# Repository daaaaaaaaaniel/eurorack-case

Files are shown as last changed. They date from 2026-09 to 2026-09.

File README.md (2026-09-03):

# eurorack-case

A parametric Eurorack case with a sloped floor in [CadQuery](https://cadquery.readthedocs.io),
ported from two Onshape Part Studios (`Eurorack v1 sym` / `asym`) and verified
against their STEP exports.

There is also a browser version at
<https://daaaaaaaaaniel.github.io/eurorack-case/> that builds the same case
without installing anything. [UserManual.md](UserManual.md) explains every
control on that page.

```
pip install cadquery
python3 build.py                                  # 26 HP, 30/30 mm walls, round lips
python3 build.py --hp 84 --front 30 --rear 80 --top-lips chamfer --tab-clearance 0.2
python3 build.py --variant asym                   # one end an integral wall, one cap
python3 -m pytest tests
```

`build.py` writes STEP and STL for each part, plus an assembly STEP, into
`output/`.

## Parts

- **case** — sloped-floor shell with T-slot rails under a 2 mm panel recess and
  counterbored M3 screw holes for the end caps. Open at both ends (`sym`), or
  closed at one end by an integral wall (`asym`, `left_wall=True`).
- **end_cap_left / end_cap_right** — 4 mm plate with a 5 mm tab that plugs into
  the shell and carries square M3 nut traps behind every screw.
- **blank_panel** — a blank module panel for checking the rail spacing.

## Configuration

The same nine inputs as the Onshape configuration, on `CaseParams`:
`hp_count`, `front_height`, `rear_height`, `top_lips` / `upper_round` /
`upper_chamfer`, `bottom_lips` / `lower_round` / `lower_chamfer`. Every other
design constant is a field too (`eurorack_case/params.py`), named after the
Onshape variable it came from.

```python
from eurorack_case import CaseParams, case, end_cap

p = CaseParams(hp_count=42, rear_height=60, top_lips="chamfer")
shell = case(p)
cap = end_cap(p, "left")
```

## Layout

- `eurorack_case/` — the model (`params.py`, `parts.py`)
- `build.py` — CLI exporter
- `tests/` — geometry checks: parts are valid, caps fit without clashing,
  screws pass the wall into the tab, nut traps sit behind them, lip styles and
  a parameter sweep build
- `viewer/` — a browser viewer (Three.js). `python3 viewer/make_viewer.py`
  embeds the exact meshes into `viewer/dist/eurorack-asym-case.html`; the page
  also rebuilds either variant in JavaScript when you move its sliders — profile
  extrusions with the screw holes, counterbores and nut traps cut by CSG
  (`viewer/vendor/csg.js`, MIT), within 0.01 % of the CadQuery volumes — and
  can save what it is showing as ASCII STL (published as a Claude artifact
  with the `downloads` capability; the host allows no `.stl` extension, so the
  file arrives as `.stl.txt` to be renamed)
- `docs/port-notes.md` — what maps to what, and where the port deliberately
  differs from the source (read this)
- `docs/port-feasibility.md` — the pre-port assessment
- `tools/fs_inventory.py` — inventory extractor for the Onshape export
- `reference/Eurorackv1asym.fs`, `Eurorackv1sym.fs` — the source FeatureScript
- `reference/onshape/` — Onshape's STEP exports of both variants, which
  `tests/test_matches_onshape.py` checks the port against
- `poc/` — the feasibility spike

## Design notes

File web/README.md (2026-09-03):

# eurorack-case-web

The case configurator as a static web app: the model in
[replicad](https://replicad.xyz) (OpenCascade compiled to wasm, running in a
web worker), a three.js viewer, and STL / STEP export straight from the
browser. Same geometry as the CadQuery model, verified against the Onshape
exports.

```
npm install
npm run dev        # http://localhost:5173
npm test           # builds every part in Node, compares with reference/onshape/*.step
npm run typecheck
npm run build      # -> dist/ (~23 MB, of which the wasm is 23 MB raw / 7 MB gzipped)
```

## Layout

- `src/model/params.ts` — `caseParams()`: the fields of `CaseParams` in
  `eurorack_case/params.py`, camel-cased, plus the derived values.
- `src/model/parts.ts` — `caseShell()`, `endCap()`, `blankPanel()`: a
  line-for-line port of `eurorack_case/parts.py`, with replicad edge finders
  where the Python matched edges by center point.
- `src/filename.ts` — `partFileName()`: a part is named for itself and the
  parameters that shape it, so two files with one name hold one geometry.
- `src/config.ts` — `buildConfig()` / `parseConfig()`: the saved settings, and
  a reader that treats an imported file as untrusted.
- `src/oc.ts` — `initOC()`: starts the wasm kernel and hands it to replicad.
- `src/worker.ts` — the modeling worker: builds the parts on request, returns
  meshes + edge lines + volumes, and writes STL/STEP on demand — one part in
  one format as itself, anything more zipped with its configuration.
- `src/scene.ts`, `src/main.ts`, `index.html` — the viewer and its controls.
- `test/matches-onshape.test.ts` — volume (1e-5), face count and bounding
  extents against Onshape's exports for both variants, plus a parameter sweep.
- `test/config.test.ts`, `test/filename.test.ts` — the configuration round trip
  (including files that are hand-edited, from a later version, or not ours) and
  the naming rule. Both run without the kernel, in milliseconds.
- `scripts/smoke.mjs` — drives the built app in headless Chromium over the
  DevTools protocol: first build, a rebuild, the asym variant, a zip download
  read back out of its central directory, a one-part zip, a config-only
  download, a single part, and a config import.

## Downloads

**Download** writes `case.zip`: the parts ticked under Parts, in STL, STEP or
both, plus a `config.json` of the settings that produced them. With nothing
ticked, the `config.json` comes down on its own. **More options** holds a
single part on its own, as a bare file. Members are named for the part and what shapes it —
`case_26hp_30mm-front_45mm-rear.stl`, `capL_30mm-front_45mm-rear.stl`,
`panel_6hp.stl` — so the caps carry no HP, being a cross-section that does not
change with the case's width.

**Import config** reads a `config.json` back and puts every control where it was,
so a case can be reprinted, or adjusted and reprinted, months later. Only the
settings the page exposes are saved; everything else follows the current model.
An imported file is checked field by field, and anything corrected is reported.

## Limits the kernel imposes

- A top lip must be smaller than the wall thickness: the wall top is only that
  wide before it drops into the panel recess, so a larger fillet has no face to
  land on. `caseParams()` refuses it; the page's slider stops at 3.5 mm.
- The end cap's 1.5 mm outer edge break is only built when the lips are modest
  (rounds ≤ 5 mm, chamfers ≤ 2 mm). Beyond that OpenCascade does not fail — it
  returns a plausible-looking solid with a wrong volume — so `endCap()` leaves
  the break off and checks the volume of what it built against the un-cut plate
  and tab. The Onshape source has the same blend and would have the same
  trouble; its defaults (1 mm) are well inside the sound region.

## Deploying to GitHub Pages

`.github/workflows/pages.yml` builds `web/`, runs the tests, and deploys
`web/dist` on every push that touches `web/` (branches `claude/replicad-port`
and `main`), or by hand from the Actions tab. One-time setup in the repository:
**Settings → Pages → Source: GitHub Actions**. The site then lives at
`https://<user>.github.io/eurorack-case/`.

The kernel is single-threaded, so no cross-origin-isolation headers are
needed — Pages can serve it as plain static files. First visit downloads the
23 MB wasm (7 MB if the CDN gzips it); after that it is cached.

## Timings

In headless Chromium on a laptop-class CPU: kernel start ~10 s on a cold
cache, first build ~2 s, a rebuild ~1–2 s, STL or STEP export well under a
second.

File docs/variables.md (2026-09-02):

# Onshape variables → `CaseParams`

The Part Studio's variable table (as shown in Onshape) against the port. "Used"
means a live sketch dimension or feature references the variable; several are
defined but never referenced, and the geometry shows what the sketches actually
drew.

| Onshape variable | value | `CaseParams` | port default | note |
|---|---|---|---|---|
| `HP_Count` | `#HP_Count0` | `hp_count` | 26 | configuration input |
| `HP` | 5.08 | `HP` (module constant) | 5.08 | |
| `CaseRearHeight` | `#RearHeight` | `rear_height` | 30 | configuration input |
| `CaseFrontHeight` | 33 | — | | **not used**: the front wall is dimensioned to the `Front_Height` configuration input (30); `front_height` |
| `CaseFrontBackThickness` | 4 | `wall_thickness` | 4 | |
| `CaseBottomThickness` | 4 | `bottom_thickness` | 4 | |
| `PanelHeight` | 129.5 | `panel_height` | 129.5 | clear width between the inner walls |
| `PanelThickness` | 2 | `panel_thickness` | 2 | depth of the panel recess |
| `PanelHoleVerticalInset` | 3 | `panel_hole_edge_inset` | 3 | |
| `RailBlockDepth` | 8 | `rail_depth` | **7.798472** | **not used**: the rail sketch carries a bare 7.798; the STEP export confirms it |
| `RailBlockHeight` | 16 | `rail_height` | **10** | **not used**: the block is drawn 10 tall; the STEP export confirms it |
| `RailBlockPanelInset` | 3 | `rail_inset` | 3 | bolt-slot axis from the inner wall |
| `RailBlockBoltWidth` | 3.2 | `rail_bolt_width` | 3.2 | |
| `RailBlockBoltDepth` | 8 | `rail_bolt_depth` | 8 | |
| `RailBlockNutWidth` | 5.8 | `rail_nut_width` | 5.8 | nut traps in the tab are cut `#RailBlockNutWidth - .1mm` |
| — | (undimensioned) | `rail_nut_slot_width` | **5.596945** | the rail's sliding-nut slot has no dimension; solved value, confirmed by the STEP |
| `RailBlockNutThickness` | 2.5 | `rail_nut_thickness` | 2.5 | |
| `RailBlockNutDepth` | 2 | `rail_nut_depth` | 2 | |
| `EndCapThickness` | `#CaseFrontBackThickness` | `end_cap_thickness` | 4 | |
| `EndCapTabThickness` | 5 | `end_cap_tab_thickness` | 5 | |
| `EndCapTabDepth` | `#BottomHoleInset + .7*#BoltCounterboreDiam` | `end_cap_tab_depth` (derived) | 8.2 | |
| `BoltThrougDiam` | 3.3 | `bolt_through_diam` | 3.3 | |
| `BoltCounterboreDiam` | 6 | `bolt_counterbore_diam` | 6 | |
| `BoltCounterboreThick` | 1.75 | `bolt_counterbore_depth` | 1.75 | |
| `BottomHoleInset` | 4 | `bottom_hole_inset` | 4 | screw axis from the case end |
| `BottomHoleSpacing` | 55 | `bottom_hole_spacing` | 55 | |
| `RearHoleSpacing` | 23 | `wall_hole_spacing` | 23 | used for both walls |
| `BaseCase` | measured, 137.5 | `outer_depth` (derived) | 137.5 | = `panel_height + 2 * wall_thickness` |
| `BaseCaseInset` | `#BaseCase - 3*#CaseFrontBackThickness` = 125.5 | — | | **not used** |
| `Railbolt_to_railbolt` | 123 | — | | **not used**; the rails are actually `panel_height - 2 * rail_inset` = 123.5 apart |
| `Rail_Length` | 56 | — | | **not used** |
| `BoltPlane_PanelEnd` | 3 | — | | **not used** |
| `UpperRoundDiam` | 2 | — | | **not used**: the fillet takes the `Upper_Round` configuration input (1); `upper_round` |
| `UpperChamfer` | 2 | — | | **not used**: the chamfer takes `Upper_Chamfer` (1); `upper_chamfer` |
| `LowerRoundDiam` | 0 | — | | drives only `Fillet 2`, which a 0 mm radius makes a no-op |
| `LowerChamfer` | 2 | — | | **not used**: the chamfer takes `Lower_Lip_Bevel` (1); `lower_chamfer` |

Configuration inputs not in the variable table: `Front_Height`, `Upper_Round`,
`Upper_Chamfer`, `Lower_Round`, `Lower_Lip_Bevel`, and the two lip-style enums —
`front_height`, `upper_round`, `upper_chamfer`, `lower_round`, `lower_chamfer`,
`top_lips`, `bottom_lips`.

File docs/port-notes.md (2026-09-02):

# Port notes

How `eurorack_case/` relates to the Onshape source, and where it deliberately
differs. Read `port-feasibility.md` first for what the source contains.

## Verified against Onshape

`reference/onshape/` holds STEP exports of both Part Studios at the default
configuration, and `tests/test_matches_onshape.py` checks the port against
them. Every part matches to better than 0.001 % in volume with identical face
counts and bounding extents:

| Onshape export | port | volume |
|---|---|---|
| `sym` Part 7 (case) | `case(CaseParams())` | 111.5710 cm³ |
| `sym` Part 6 / endcap | `end_cap(p, "left")` / `"right"` | 21.7197 cm³ |
| `asym` case | `case(CaseParams(left_wall=True))` | 128.4112 cm³ |
| `asym` endcap | `end_cap(p, "right")` | 21.7197 cm³ |

## The two Part Studios

`Eurorack v1 sym` and `Eurorack v1 asym` are the same design with different
ends, not different wall heights (both default to 30/30 mm):

- **sym** — shell open at both ends, two removable end caps. `left_wall=False`.
- **asym** — X = 0 closed by an integral 4 mm wall with the outer profile, one
  removable cap at the far end, no screw holes at the closed end. `left_wall=True`.

The `sym` source is the `asym` source plus four features (`Plane 1`, `Split 4`,
`Mirror 3`, `Boolean 1`) that cut the shell at mid-length and mirror the open
half over the walled one.

## The parts

| part | Onshape origin |
|---|---|
| `case()` | `Case profile` + `Rail block profile` extruded `#HP_Count*#HP`; the C-cap end wall is discarded by `Split 1` / `Mirror 2`, which reflect one half of the shell onto the other, so the shell ends up open at both ends |
| `end_cap(end)` | `Endcap ex` (4 mm plate, `C-cap profile`) + `Endcap tab ex` (5 mm U-band, `End cap tab profile`, `#EndCapTabDepth` deep) with the nut traps from `Sketch 4`, `Rear Bolt Capture`, `Sketch 6` |
| `blank_panel(hp)` | `panel` / `panel thick` / the Ø3.2 hole feature — a 6 HP test panel |

Screws: `bottom hole setup 1/2`, `front hole setup`, `rear hole setup` and the
patterns that follow them. Ø3.3 through, Ø6 × 1.75 counterbore on the outside,
axis `#BottomHoleInset` (4 mm) in from each end so it lands inside the 8.2 mm
tab; a `#RailBlockNutWidth - .1mm` square trap 2 mm deep on the tab's inner face.

## Frame

X along the rails (0 → `width`), Y front (−) to rear (+) centred on the panel,
Z up with the wall tops at Z = 0. The source's Right-plane sketches map to the
YZ plane here; its `Rightplane` x is this Y and its y is this Z.

## Where the port differs from the source, on purpose

**Ends are built directly.** The sources build an integral wall, then (in `sym`)
split the shell and mirror the open half over it. The port builds each end as
asked — the same result, none of the history.

**Bottom screws: three counterbores, centred.** The source patterns 3 through
holes but only 2 counterbores, and both patterns run one way from the floor's
midpoint rather than being centred, which puts one instance off the part. The
port cuts three counterbored screws at 0 and ±`bottom_hole_spacing` along the
floor. Same holes as the source at the default configuration.

**Wall screws: as many as fit.** The source fixes 1 screw on the front wall and
3 on the rear at `#RearHoleSpacing`, starting from the wall's mid-height. With
the default 30 mm rear wall the 2nd and 3rd rear holes fall off the part. The
port starts at mid-height, patterns at `wall_hole_spacing` in both directions,
and keeps every position whose nut trap fits in the tab's leg (between the
underside of the rail and the tab's floor). That gives 1 per wall at 30 mm and
3 at 80 mm, which is what the source's initial-guess geometry shows the author
working with.

**Upper chamfer on both top edges.** `Chamfer 1` in the source only selects the
front top edge; `Fillet 1` selects both. The port treats front and rear alike
for both styles.

**Minimum wall height is 21 mm, not 15.** Below panel recess + rail + floor +
tab (2 + 10 + 4 + 5) the end cap tab has nowhere to go and the source's own
geometry would self-intersect there. `CaseParams` refuses it.

**`Fillet 2` is dropped.** It is unconditional in the source but its radius is
`#LowerRoundDiam = 0 mm`, so it never produced geometry.

**`Chamfer 2` only breaks the removable cap's outer face.** The source selects
the outer face of the integral wall too, but the `asym` STEP shows no chamfer
there, so that reference must fail silently in Onshape. The port follows the
export.

**Two un-round numbers are kept as they are.** The rail block is 7.798 mm deep
(`rail_depth`) and its sliding-nut slot is 5.597 mm wide (`rail_nut_slot_width`).
Neither is dimensioned in the source sketch — the block was drawn with a bare
value and the slot width is unconstrained — so these are what the solver left,
and the STEP exports carry them. The `RailBlockDepth` variable (8 mm) is never
referenced. Both are named parameters; set them to 8.0 and 5.6 if those were the
intent. The nut *traps* in the end cap tab are a separate, dimensioned 5.7 mm.

**Variables the source defines but never uses** — `RailBlockHeight` (16, the
rail is actually 10 tall), `Rail_Length`, `Railbolt_to_railbolt`, `BaseCase`,
`BaseCaseInset`, `UpperRoundDiam`, `LowerRoundDiam`, `UpperChamfer`,
`LowerChamfer`, `BoltPlane_PanelEnd` — are not carried over.

## Not ported

**The tail of the `asym` tree** (`Mirror 1`, `2x tab connect`, `endcap tab
connect`, `Split 2/3`, `Extrude 10–17`): read literally these fuse the tab into
the shell and extend it by 25–35 mm. The exported parts show none of that — the
end cap is a separate 21.72 cm³ part in both variants — so they are dead edits
and the port ignores them.

**The floor bracket** (`Sketch 2`, `Extrude 1–3`, `Sketch 8`, the mate
connectors and `Transform 1–4`): a 40 × 20 × 2 mm plate with two 6 mm steps and
two Ø2 holes, positioned on the case floor by mate connector. Its purpose is not
recorded, only two of its dimensions are constrained, and which sketch regions
get which step height is not recoverable from the export's region references.
If it is still wanted, describe it and it is a ten-line function.

**PSU mounts** and everything downstream of them (10 features) — retired in the
source, confirmed not wanted.

## Worth checking on the source design

**Rail spacing vs. real modules.** The bolt slots sit `rail_inset` = 3 mm from
the inner walls, so their axes are `panel_height − 6` = 123.5 mm apart. The
Eurorack standard is 122.5 mm (128.5 mm panel, holes 3 mm from the edge). A
standard module centred in the 129.5 mm recess therefore lands 0.5 mm outside a
3.2 mm slot. The port reproduces the source; the blank panel it builds matches
the rails, a bought module may not. Changing `panel_height` to 128.5 fixes both
the spacing and the recess width at once.

**Zero tab clearance.** The tab is modelled to the exact cavity size, as in the
source. `tab_clearance` shrinks it for a printable fit.

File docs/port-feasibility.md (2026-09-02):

# Porting `Eurorackv1asym` from FeatureScript to CadQuery — feasibility

> Written before the port. The port itself lives in `eurorack_case/`; see
> `port-notes.md` for what was done and where it deviates.

**Verdict: yes, it is possible — but it is a re-implementation, not a translation.**

Nothing in the model needs geometry CadQuery/OCCT cannot produce. Everything is
prismatic: rectilinear profiles, blind extrudes, booleans, linear patterns,
constant-radius fillets and equal-offset chamfers. There is no loft, sweep,
helix, draft, shell, variable fillet, or freeform surface anywhere in the export.

What does *not* survive the move is the way Onshape *refers* to geometry. That is
the whole cost of the job, and it is why the export cannot be mechanically
converted.

## What the export actually contains

Generated by `tools/fs_inventory.py`; full dump in `docs/inventory.txt`.

| | count |
|---|---|
| features | 118 |
| — variable assignments (`assignVariable`) | 35 |
| — sketches | 20 |
| — extrudes | 28 |
| — booleans | 6 |
| — linear patterns | 6 |
| — fillets / chamfers | 4 / 3 (one fillet is dead) |
| — split parts / mirrors | 3 / 2 |
| — holes | 3 |
| — transforms | 4 |
| — construction planes / mate connectors | 2 / 2 |
| sketch entities | 148 lines, 30 points, 8 circles |
| sketch constraints | 435 |
| — of which are *driving dimensions* | 54 |
| topological references (`qCompressed`) | 278 (146 zlib-compressed) |
| features contributing nothing to this configuration | 10 |

Nine configuration inputs drive the model:

| input | key | type |
|---|---|---|
| HP_Count | `HP_Count0` | integer, 2–200 (default 26) |
| Front Height | `Front_Height` | length, 15–200 mm (default 30) |
| Rear Height | `RearHeight` | length, 30–150 mm (default 30) |
| Top Lips | `List_sltuiwY7bs5tJx` | enum: Round / Sharp / Chamfer |
| Upper Round | `Upper_Round` | length, 0.5–10 mm |
| Upper Chamfer | `Upper_Chamfer` | length, 0.5–10 mm |
| Bottom Lips | `List_5KGcbwyvF0AOZo` | enum: Round / Sharp / Chamfer |
| Lower Round | `Lower_Round` | length, 0.5–15 mm |
| Lower Chamfer | `Lower_Lip_Bevel` | length, 0.5–10 mm |

## What ports cleanly

**The variable table.** 35 variables, all scalar lengths or counts, with
readable expressions preserved in the export (`#BottomHoleInset+(.7*#BoltCounterboreDiam)`).
These become a Python dataclass or plain module constants. Direct, mechanical.

**Sketch profiles.** 435 constraints looks alarming, but only 54 of them are
driving dimensions — the rest are coincident/parallel/perpendicular/mirror
constraints that exist because Onshape needs a solver and CadQuery does not. In
CadQuery you write the solved coordinates as a `polyline`, and "parallel" is a
consequence of the coordinates rather than a constraint to satisfy. There is
exactly one `TANGENT` constraint in the entire model.

**Sketch planes.** All 20 sketches sit on either a default plane (`Right`, `Top`)
or a planar face of an earlier extrude — and the export records *which sketch
edge generated that face*. So every plane is reconstructible arithmetically from
the parameters; none depends on a fillet face, a swept face, or anything whose
position is hard to predict.

**Extrudes, booleans, patterns, mirrors, splits, holes.** One-to-one with
`extrude` / `cut` / `union` / `intersect`, list comprehensions over translated
copies, `mirror`, and `Workplane.hole`. The holes are plain blind holes
(Ø3.2×3.5 and Ø2×2.7; a third, Ø2×5, is dead — see below) — no counterbore,
countersink, or thread, despite the `hole()` feature carrying Onshape's full
tapping parameter block.

## What has to be rebuilt by hand

**The 278 `qCompressed` queries.** These are Onshape's topological-naming
references. Decompressed, one reads:

```
QueryM5 disambiguationData[ disambiguationType TOPOLOGY entities[
  derivedFrom{ entityType EDGES historyType CREATION
               operationId F3HD5PxY3AAr9PG_3wireOp
               queryType SKETCH_ENTITY sketchEntityId IAhQH5pdcXoa0.MirrorCS }
  imprint IMPRINT ... ]]
```

That is "the edge produced by imprinting the mirrored sketch entity
`IAhQH5pdcXoa0` from the rail block profile sketch." CadQuery has no persistent
naming and no equivalent concept. Every one of these has to be replaced by a
geometric selector (`>Z`, `|Y`, `NearestToPointSelector`, a box selector, or a
lambda over edge midpoints).

This is the real work, and it concentrates in the fillet/chamfer features —
6 live ones selecting 20 edges between them. The rest of the queries pick sketch regions
and extrude targets, where the substitute is usually just "build that profile as
its own `Workplane`."

**Region selection.** Several sketches are extruded region-by-region with
different depths — the end-cap profile sketch `FNqrsvGVGM0ZkbD_3` alone feeds
eight extrudes at 25 and 35 mm. Onshape splits a sketch into regions
automatically where lines cross; CadQuery does not. Each region has to be
authored as a separate closed profile.

**`BaseCase` is a measured variable.** It is `VariableMode.MEASURED` — its value
comes from measuring the model, and the export literally stores `"?"` for it.
`BaseCaseInset = #BaseCase - 3*#CaseFrontBackThickness` depends on it. This has
to be re-derived analytically (or read back with a bounding-box query mid-build).

**`TransformType.TRANSFORM_MATE_CONNECTORS`.** One transform positions a body by
mapping one mate connector onto another. CadQuery has no mate connectors; this
becomes an explicit `cq.Location` computed from the same reference geometry.

**Configuration-driven branching.** Four features are switched on by the Top Lips
and Bottom Lips enums — `Fillet 1` / `Chamfer 1` for the top, `Lower Edges
Fillet` / `Lower Lip Chamf` for the bottom. These become `if` branches on the
enum value, as in the spike.

## What does not need porting at all

Four features are hard-suppressed (`if (false)`): `endcap tab sizing`,
`Sketch 3`, `PSU mounts`, `Extrude 6`. The PSU mounting provisions belong to an
older revision of the design and are not wanted.

Suppression propagates, and silently — the export wraps every feature call in
`try(...)`, so a live feature that references suppressed geometry simply fails
and is swallowed. Six more features are dead for that reason:

| feature | why |
|---|---|
| `Extrude 4` | consumes `Sketch 3` |
| `Extrude 5` | consumes `PSU mounts` |
| `Sketch 5` | placed on a face of `PSU mounts` |
| `Fillet 4` | rounds edges created by `Sketch 5` |
| `Sketch 7` | placed on a face of `PSU mounts` |
| the Ø2×5 hole | located from `Sketch 7` |

So 10 of 118 features are dead weight, including one of the four fillets and one
of the three holes. Skipping them takes the fillet/chamfer count that needs
hand-written edge selectors from 7 to 6, and the holes from 3 to 2.
`tools/fs_inventory.py` computes this list, so it stays accurate if the model is
re-exported.

## Spike

`poc/spike_case_shell.py` exercises the three mechanics that have no direct
equivalent — hand-written slanted profile, parameter-driven extrude length, and
subset edge selection for the fillet/chamfer enum — on CadQuery 2.8.0:

```
sharp    valid=True volume= 200.99 cm3 faces= 12 edges= 24 bbox=128.50 x 132.08 x 62.40 mm
round    valid=True volume= 200.77 cm3 faces= 14 edges= 30 bbox=128.50 x 132.08 x 62.40 mm
chamfer  valid=True volume= 200.47 cm3 faces= 14 edges= 30 bbox=128.50 x 132.08 x 62.40 mm
STEP export OK
```

All three lip variants build a valid solid and export to STEP. The selector
`.edges("|Y").edges(">Z")` picks exactly the intended 2 edges. It is a stand-in
shape, not the real case wall.

## Suggested approach

1. Port the variable table verbatim. Cheap, and it makes everything downstream readable.
2. Rebuild the two root sketches — `Case profile` (10 entities) and
   `Rail block profile` (50 entities) — as parametric functions returning
   `Workplane` profiles. These drive most of the model.
3. Build the case body, end caps, and rails as separate functions returning
   solids, assembled with booleans, rather than mirroring Onshape's flat
   feature-by-feature order. The Onshape ordering is an artifact of interactive
   modelling and reproducing it faithfully would make the Python harder to read
   than the geometry warrants.
4. Do the fillets and chamfers last, with named selector helpers, and assert the
   selected edge count in each — a silently-wrong selector is the most likely
   defect in a port like this, and an `assert n == 4` catches it at the parameter
   values where it breaks.
5. Validate against Onshape by exporting STEP from both at matched parameter
   values and comparing volume, bounding box, and face/edge counts. Do this
   across the parameter range, not just at the default — the fillet selectors
   are the thing that will break when `Front_Height` or `HP_Count` moves.

## Cost and risk

Roughly 700–1000 lines of CadQuery. The bulk is transcribing profile coordinates
and re-deriving the ~24 fillet/chamfer edge selections; neither is difficult,
both are tedious and want checking against the original.

The one thing to decide up front: **how faithful does the port need to be?**
Matching the Onshape output to within a tolerance across the whole parameter
range is materially more work than producing a clean parametric case that makes
the same parts. If the goal is a usable parametric Eurorack case in Python, the
second is the better target and roughly half the effort.

## Reproducing this analysis

```
pip install cadquery
python3 tools/fs_inventory.py reference/Eurorackv1asym.fs   # regenerates docs/inventory.txt
python3 poc/spike_case_shell.py
```

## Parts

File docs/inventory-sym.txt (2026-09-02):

== configuration inputs ==
  HP_Count         HP_Count0                isInteger
  Front Height     Front_Height             isLength
  Rear Height      RearHeight               isLength
  Upper Round      Upper_Round              isLength
  Upper Chamfer    Upper_Chamfer            isLength
  Lower Round      Lower_Round              isLength
  Lower Chamfer    Lower_Lip_Bevel          isLength
  Top Lips         List_sltuiwY7bs5tJx      enum List_sltuiwY7bs5tJx_conf
  Bottom Lips      List_5KGcbwyvF0AOZo      enum List_5KGcbwyvF0AOZo_conf

== variables ==
  HP_Count                 ASSIGNED  = #HP_Count0
  RearHoleSpacing          ASSIGNED  = 23 mm
  BottomHoleInset          ASSIGNED  = 4 mm
  BoltCounterboreThick     ASSIGNED  = 1.75 mm
  BoltCounterboreDiam      ASSIGNED  = 6 mm
  HP                       ASSIGNED  = 5.08 mm
  RailBlockDepth           ASSIGNED  = 8 mm
  RailBlockHeight          ASSIGNED  = 16 mm
  RailBlockNutThickness    ASSIGNED  = 2.5 mm
  RailBlockNutWidth        ASSIGNED  = 5.8 mm
  RailBlockBoltWidth       ASSIGNED  = 3.2mm
  RailBlockNutDepth        ASSIGNED  = 2 mm
  RailBlockBoltDepth       ASSIGNED  = 8 mm
  RailBlockPanelInset      ASSIGNED  = 3 mm
  BoltPlane_PanelEnd       ASSIGNED  = 3 mm
  CaseBottomThickness      ASSIGNED  = 4 mm
  CaseFrontBackThickness   ASSIGNED  = 4 mm
  CaseRearHeight           ASSIGNED  = #RearHeight
  CaseFrontHeight          ASSIGNED  = 33 mm
  PanelHeight              ASSIGNED  = 129.5 mm
  Rail_Length              ASSIGNED  = 56 mm
  Railbolt_to_railbolt     ASSIGNED  = 123 mm
  PanelThickness           ASSIGNED  = 2 mm
  PanelHoleVerticalInset   ASSIGNED  = 3 mm
  EndCapThickness          ASSIGNED  = #CaseFrontBackThickness
  EndCapTabThickness       ASSIGNED  = 5 mm
  EndCapTabDepth           ASSIGNED  = #BottomHoleInset+(.7*#BoltCounterboreDiam)
  BoltThrougDiam           ASSIGNED  = 3.3 mm
  BottomHoleSpacing        ASSIGNED  = 55 mm
  BaseCase                 MEASURED  = \"?\"
  BaseCaseInset            ASSIGNED  = #BaseCase-(3*#CaseFrontBackThickness)
  UpperRoundDiam           ASSIGNED  = 2 mm
  LowerRoundDiam           ASSIGNED  = 0 mm
  UpperChamfer             ASSIGNED  = 2 mm
  LowerChamfer             ASSIGNED  = 2 mm

== sketches ==
  F3HD5PxY3AAr9PG_3          Rail block profile      50 entities   plane: default plane (Rightplane)
  FiGsjAS4K608afc_0          Case profile            10 entities   plane: default plane (Rightplane)
  Foyk2i1MdWTnpLh_2          C-cap profile            4 entities   plane: face traced to sketch (F3HD5PxY3AAr9PG_3)
  FNqrsvGVGM0ZkbD_3          End cap tab profile      9 entities   plane: face traced to sketch (F3HD5PxY3AAr9PG_3)
  FkHd7zO9gFunJkQ_4          bottom hole setup 1      4 entities   plane: face traced to sketch (FiGsjAS4K608afc_0)
  FcjJB77x9zw5ukM_4          bottom hole setup 2      4 entities   plane: face traced to sketch (FiGsjAS4K608afc_0)
  FEgylpGpriUs7TI_4          front hole setup         7 entities   plane: face traced to sketch (FiGsjAS4K608afc_0)
  FPs6SSSPjT9zNdc_4          rear hole setup          9 entities   plane: face traced to sketch (FiGsjAS4K608afc_0)
  FtBciP4FdsrYK6w_6          panel                    4 entities   plane: face traced to sketch (F3HD5PxY3AAr9PG_3)
  FlpU4qVtZLrTCze_7          panel holes              8 entities   plane: face traced to sketch (FtBciP4FdsrYK6w_6)
  Fga1cnVS33C7GRM_7          Sketch 4                15 entities   plane: face traced to sketch (FNqrsvGVGM0ZkbD_3)
  F8wggogTepNUM5x_7          Rear Bolt Capture       15 entities   plane: face traced to sketch (FNqrsvGVGM0ZkbD_3)
  FvWr5emyZpPuFch_7          Sketch 6                 5 entities   plane: face traced to sketch (FNqrsvGVGM0ZkbD_3)
  Fqk6yoVrBbiGN3j_7          Sketch 1                 0 entities   plane: face traced to sketch (Foyk2i1MdWTnpLh_2)
  FlO66UHASJM1bnu_7          Sketch 2                12 entities   plane: default plane (Topplane)
  FXkKXyVAhY2dCez_8          Sketch 3                 6 entities   plane: face traced to sketch (FlO66UHASJM1bnu_7)
  FDazl34QFPYVJeX_8          PSU mounts              11 entities   plane: face traced to sketch (FNqrsvGVGM0ZkbD_3)
  FT56TNE8MwTVFtD_8          Sketch 5                 6 entities   plane: default plane (Rightplane)
  Ff3uAryMmkQtUPP_8          Sketch 8                 3 entities   plane: face traced to sketch (FlO66UHASJM1bnu_7)
  FnPuTavsx1H4H3I_8          Sketch 7                 4 entities   plane: face traced to sketch (FDazl34QFPYVJeX_8)

== solid features ==
  L972   extrude         Case + blocks ex       operationType=NEW bodyType=SOLID endBound=BLIND depth=#HP_Count*#HP nEntities=3
  L991   booleanBodies   Case + blocks union    operationType=UNION
  L1075  extrude         C-cap ex               operationType=NEW bodyType=SOLID endBound=BLIND depth=#EndCapThickness nEntities=2
  L1092  booleanBodies   Case + cap union       operationType=UNION
  L1260  extrude         Endcap tab ex          operationType=NEW bodyType=SOLID endBound=BLIND depth=#EndCapTabDepth nEntities=1
  L1279  extrude         Endcap ex              operationType=NEW bodyType=SOLID endBound=BLIND depth=#EndCapThickness nEntities=1
  L1296  cPlane          interior bottom plane  width=150 mm nEntities=2
  L1456  extrude         bottom counterbore     operationType=NEW bodyType=SOLID endBound=BLIND depth=#BoltCounterboreThick nEntities=2
  L1475  linearPattern   bottom cb pattern      operationType=REMOVE patternType=PART distance=#BottomHoleSpacing instanceCount=2 nEntities=1
  L1490  extrude         bottom through         operationType=NEW bodyType=SOLID endBound=BLIND depth=10 mm nEntities=1
  L1511  linearPattern   bottom through pattern operationType=REMOVE patternType=PART distance=#BottomHoleSpacing instanceCount=3 nEntities=1
  L1599  extrude         front counterbore      operationType=NEW bodyType=SOLID endBound=BLIND depth=#BoltCounterboreThick nEntities=2
  L1618  linearPattern   front cb pattern       operationType=REMOVE patternType=PART distance=#RearHoleSpacing instanceCount=1 nEntities=1
  L1633  extrude         front through          operationType=NEW bodyType=SOLID endBound=BLIND depth=25 mm nEntities=1
  L1650  linearPattern   front through pattern  operationType=NEW patternType=PART distance=#RearHoleSpacing instanceCount=1 nEntities=1
  L1669  booleanBodies   front through cut      operationType=SUBTRACTION
  L1783  extrude         Rear Counterbore       operationType=NEW bodyType=SOLID endBound=BLIND depth=#BoltCounterboreThick nEntities=2
  L1802  linearPattern   Rear CB pattern        operationType=REMOVE patternType=PART distance=#RearHoleSpacing instanceCount=3 nEntities=1
  L1817  extrude         Rear through           operationType=NEW bodyType=SOLID endBound=BLIND depth=10 mm nEntities=1
  L1838  linearPattern   rear cb cut            operationType=REMOVE patternType=PART distance=#RearHoleSpacing instanceCount=3 nEntities=1
  L1911  fillet          Fillet 1               filletType=EDGE radius=#Upper_Round width=5 mm nEntities=4
  L1932  fillet          Fillet 2               filletType=EDGE radius=#LowerRoundDiam width=5 mm nEntities=4
  L1949  chamfer         Chamfer 1              chamferType=EQUAL_OFFSETS width=#Upper_Chamfer nEntities=2
  L1968  mirror          Mirror 1               operationType=NEW patternType=PART nEntities=1
  L1985  booleanBodies   2x tab connect         operationType=UNION
  L2002  booleanBodies   endcap tab connect     operationType=UNION
  L2029  booleanBodies   endcap tab sizing      operationType=SUBTRACTION
  L2104  extrude         panel thick            operationType=NEW bodyType=SOLID endBound=BLIND depth=2 mm nEntities=3
  L2232  hole            #featureName           holeDiameterV3=3.2 mm holeDepthV3=3.5 mm
  L2409  extrude         Extrude 7              operationType=REMOVE bodyType=SOLID endBound=BLIND depth=#RailBlockNutDepth nEntities=3
  L2549  extrude         Extrude 8              operationType=REMOVE bodyType=SOLID endBound=BLIND depth=#RailBlockNutDepth nEntities=3
  L2630  extrude         Extrude 9              operationType=REMOVE bodyType=SOLID endBound=BLIND depth=#RailBlockNutDepth nEntities=1
  L2651  fillet          Lower Edges Fillet     filletType=EDGE radius=#Lower_Round width=5 mm nEntities=4
  L2805  extrude         Extrude 1              operationType=NEW bodyType=SOLID endBound=BLIND depth=2 mm nEntities=3
  L2826  extrude         Extrude 2              operationType=ADD bodyType=SOLID endBound=BLIND depth=6 mm nEntities=2
  L2845  extrude         Extrude 3              operationType=ADD bodyType=SOLID endBound=BLIND depth=6 mm nEntities=1
  L2934  extrude         Extrude 4              operationType=ADD bodyType=SOLID endBound=BLIND depth=10 mm nEntities=2
  L2951  mateConnector   Mate connector 1       
  L2968  mateConnector   Mate connector 2       
  L2985  transform       Transform 3            transformType=ROTATION distance=25 mm nEntities=1
  L3004  transform       Transform 1            transformType=TRANSFORM_MATE_CONNECTORS distance=25 mm nEntities=1
  L3019  transform       Transform 2            transformType=TRANSLATION_3D distance=25 mm nEntities=1
  L3164  extrude         Extrude 5              operationType=ADD bodyType=SOLID endBound=UP_TO_SURFACE depth=25 mm nEntities=4
  L3249  extrude         Extrude 6              operationType=REMOVE bodyType=SOLID endBound=BLIND depth=25 mm nEntities=1
  L3270  fillet          Fillet 4               filletType=EDGE radius=3 mm width=5 mm nEntities=4
  L3285  transform       Transform 4            transformType=TRANSLATION_3D distance=25 mm nEntities=1
  L3348  hole            #featureName           holeDiameterV3=2 mm holeDepthV3=2.7 mm
  L3369  chamfer         Lower Lip Chamf        chamferType=EQUAL_OFFSETS width=#Lower_Lip_Bevel nEntities=4
  L3386  chamfer         Chamfer 2              chamferType=EQUAL_OFFSETS width=1.5 mm nEntities=2
  L3472  hole            #featureName           holeDiameterV3=2 mm holeDepthV3=5 mm
  L3489  cPlane          Plane 1                width=150 mm nEntities=2
  L3506  splitPart       Split 4                splitType=PART
  L3527  mirror          Mirror 3               operationType=NEW patternType=PART nEntities=2
  L3544  booleanBodies   Boolean 1              operationType=UNION
  L3562  cPlane          Plane 2                width=150 mm nEntities=2
  L3579  splitPart       Split 1                splitType=PART
  L3598  mirror          Mirror 2               operationType=ADD patternType=PART nEntities=1
  L3615  splitPart       Split 2                splitType=PART
  L3632  splitPart       Split 3                splitType=PART
  L3649  extrude         Extrude 10             operationType=ADD bodyType=SOLID endBound=BLIND depth=25 mm nEntities=1
  L3666  extrude         Extrude 11             operationType=ADD bodyType=SOLID endBound=BLIND depth=25 mm nEntities=1
  L3683  extrude         Extrude 12             operationType=ADD bodyType=SOLID endBound=BLIND depth=35 mm nEntities=1
  L3700  extrude         Extrude 13             operationType=ADD bodyType=SOLID endBound=BLIND depth=35 mm nEntities=1
  L3719  extrude         Extrude 14             operationType=REMOVE bodyType=SOLID endBound=BLIND depth=25 mm nEntities=1
  L3740  extrude         Extrude 15             operationType=ADD bodyType=SOLID endBound=UP_TO_SURFACE depth=25 mm nEntities=1
  L3759  extrude         Extrude 16             operationType=REMOVE bodyType=SOLID endBound=BLIND depth=25 mm nEntities=1
  L3780  extrude         Extrude 17             operationType=ADD bodyType=SOLID endBound=UP_TO_SURFACE depth=25 mm nEntities=1

== conditional / suppressed features ==
  Fillet 1               FCjQYeNCXzbMZup_4          guard: !switch (configuration.List_sltuiwY7bs5tJx) { List_sltuiwY7bs5tJx_conf.Default : false, List_sltuiwY7bs5tJx_co
  Chamfer 1              FRwPt9qVczpM9nA_4          guard: !switch (configuration.List_sltuiwY7bs5tJx) { List_sltuiwY7bs5tJx_conf.Default : true, List_sltuiwY7bs5tJx_con
  endcap tab sizing      F1AiqOmUxEkecER_6          guard: false
  Lower Edges Fillet     FHpmxK3OWCIyRoo_7          guard: !switch (configuration.List_5KGcbwyvF0AOZo) { List_5KGcbwyvF0AOZo_conf.Default : false, List_5KGcbwyvF0AOZo_co
  Sketch 3               FXkKXyVAhY2dCez_8          guard: false
  PSU mounts             FDazl34QFPYVJeX_8          guard: false
  Extrude 6              FZDqRtSbp8Wsf7q_8          guard: false
  Lower Lip Chamf        F4q7MG087crPxlb_8          guard: !switch (configuration.List_5KGcbwyvF0AOZo) { List_5KGcbwyvF0AOZo_conf.Default : true, List_5KGcbwyvF0AOZo_con

== features contributing nothing to this configuration: 10 ==
  endcap tab sizing      F1AiqOmUxEkecER_6          suppressed
  Sketch 3               FXkKXyVAhY2dCez_8          suppressed
  Extrude 4              Fw1a6UVuNIfMqbB_8          depends on a suppressed feature
  PSU mounts             FDazl34QFPYVJeX_8          suppressed
  Extrude 5              FiC6SElq5R48HuP_8          depends on a suppressed feature
  Sketch 5               FT56TNE8MwTVFtD_8          depends on a suppressed feature
  Extrude 6              FZDqRtSbp8Wsf7q_8          suppressed
  Fillet 4               FHdXRlIvMxW4HKb_8          depends on a suppressed feature
  Sketch 7               FnPuTavsx1H4H3I_8          depends on a suppressed feature
  #featureName           F4ActNE3PHJY9a0_8          depends on a suppressed feature

== sketch constraints ==
   182  COINCIDENT
    45  MIRROR
    44  PARALLEL
    28  MIDPOINT
    25  LENGTH
    24  PERPENDICULAR
    24  HORIZONTAL
    18  DISTANCE
    10  EQUAL
     9  VERTICAL
     8  PROJECTED
     6  DIAMETER
     5  OFFSET
     5  CONCENTRIC
     1  TANGENT
     1  LINEAR_PATTERN

== driving dimensions: 54 (7 carry no expression) ==
    4  #BoltCounterboreDiam
    3  2 mm
    3  #EndCapTabThickness
    3  #BottomHoleInset
    3  #BoltThrougDiam
    3  #RailBlockNutWidth-.1mm
    2  #CaseFrontBackThickness
    2  3 mm
    2  40 mm
    2  5 mm
    2  16 mm
    1  #PanelHeight
    1  #PanelThickness
    1  #PanelHoleVerticalInset
    1  #RailBlockNutWidth
    1  #RailBlockNutDepth
    1  #RailBlockNutThickness
    1  #RailBlockBoltDepth
    1  #RailBlockBoltWidth
    1  #CaseRearHeight
    1  #Front_Height
    1  #CaseBottomThickness
    1  #RailBlockBoltDepth+2mm+2mm+(.5*#BoltCounterboreDiam)
    1  7.5 mm
    1  20 mm
    1  4.75 mm
    1  25 mm
    1  12 mm
    1  0 mm

== topological references: 288 qCompressed queries (154 zlib-compressed) ==

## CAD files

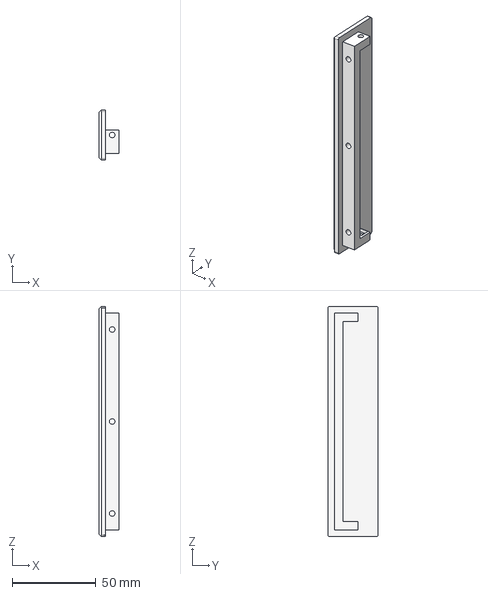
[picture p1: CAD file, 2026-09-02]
reference/onshape/sym-endcap-left.step
12.2 x 30.0 x 137.5 mm

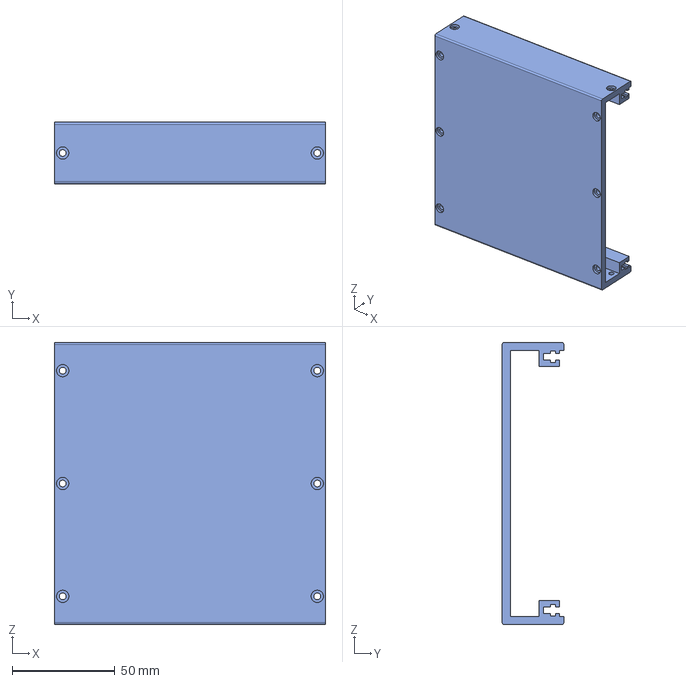
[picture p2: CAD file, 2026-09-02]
reference/onshape/sym-case.step
132.1 x 30.0 x 137.5 mm

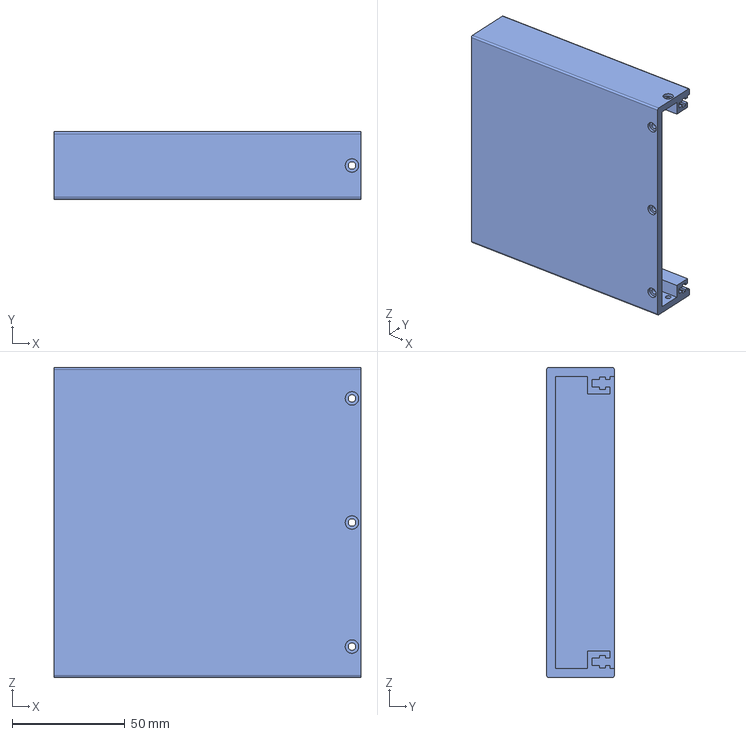
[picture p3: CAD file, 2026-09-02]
reference/onshape/asym-case.step
136.1 x 30.0 x 137.5 mm

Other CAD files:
reference/onshape/asym-endcap.step
reference/onshape/sym-endcap-right.step

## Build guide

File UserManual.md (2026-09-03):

# Eurorack Case Preview — user manual

This is a guide to every control on the web page at
<https://daaaaaaaaaniel.github.io/eurorack-case/>. The page builds a 3D-printable
Eurorack case to your measurements, shows it to you in 3D, and hands you the
files to print. Nothing is uploaded: the model is built inside your browser.

The page has two halves. The **3D view** on the left shows the case. The
**side panel** on the right holds the controls, in the order described below.

---

## The 3D view

**LOADING…** appears in the middle of the view while the modeling engine
starts. That takes a few seconds the first time. Once the first case appears,
the page is ready.

**Mouse.** Drag with the left button to orbit around the case. Scroll to zoom.
Drag with the right button to pan. The reminder in the bottom-right corner,
"drag orbit · wheel zoom · right-drag pan", says the same thing.

**View buttons** (bottom-left): **Iso**, **Front**, **Top** and **End** snap
the camera to a standard angle and re-frame the whole case.

**The title block** (top-left) shows the page title, then a one-line summary
of the case now on screen, for example `26 HP · 30/30 mm · symmetric`, and under
that how long the last build took. While a rebuild is running the line reads
"Building…" with a pulsing dot. If a build fails, the reason appears here in red
and the previous case stays on screen.

Every change you make in the side panel rebuilds the case, which usually takes
one to three seconds.

---

## Display

Settings here change only how the preview looks. They have no effect on the
printed parts or on the downloaded files. The small circled **i** beside the
heading says the same thing when you hover over it or click it.

**Case color.** Click the swatch to open a color picker and choose a new color
for the case body. This color is also used for the page's highlights, such as
slider knobs and status text, so the panel matches the model.

**End cap color.** Click the swatch to pick the color of the end caps.

**Explode.** Drag the slider to the right to pull the parts apart so you can see
how they fit together. At 0 the case is assembled; at 1 it is fully spread out.
This only moves things in the preview.

---

## Parts

Three checkboxes, one per printable part, each with a color swatch and its
volume in cubic centimeters:

- **Case** — the mid section: the floor, the two long walls and the rails.
- **End caps** — the removable end plates (one or two, see *Side panels*).
- **Blank panel** — a plain module panel of the width set under *Parameters*,
  useful as a test print or to fill an empty slot.

Ticking a box **shows** that part in the 3D view **and includes it** in the zip
you get from Download. Unticking a box hides it and leaves it out of the zip.
The circled **i** beside the heading reminds you of this.

**Selected total** adds up the volume of the ticked parts. Multiply by your
filament's density to estimate material.

---

## Parameters

These sliders and dropdowns set the shape of the case. Every change rebuilds
the model.

**Side panels.** Choose how the ends of the case are made.

- *Symmetric (both detachable)* — both ends are separate end caps, screwed on.
  You print one case plus two caps.
- *Asymmetric (right detachable)* — the left end is a fixed wall printed as
  part of the case; only the right end is a removable cap. You print one case
  plus one cap. Choose this if you want a case that can only be opened from
  one side, or to save a part.

**Width.** The width of the case in HP (horizontal pitch, the Eurorack unit:
1 HP = 5.08 mm). Range 2 to 168 HP. Two lines under the slider give the result
in millimeters:

- the first is the length of the case mid section on its own;
- the second, marked "with end caps", is the assembled length including the
  end caps.

**Front height** and **Rear height.** The height of the front and rear walls in
millimeters, 21 to 200 mm each. Set them equal for a flat case, or make the rear
taller to tilt the modules toward you. Under *Rear height* a line reports the
result: "Panel is level" or "Panel tilts 20.0° toward front".

**Top lips** and **Bottom lips.** The shape of the edges along the top of the
walls and along the bottom of the case. Each has a dropdown and a size slider.

- *Round* — a rounded edge, with the slider setting its radius.
- *Chamfer* — a 45° flat cut, with the slider setting its size.
- *Sharp* — a plain square edge. The slider is greyed out because there is
  nothing to size.

Top lips run from 0.5 to 3.5 mm; bottom lips from 0.5 to 10 mm. Very large lips
can be impossible to build, in which case the title block says so and the
previous case stays on screen; choose a smaller size.

**Tab clearance.** Each end cap has a tab that slides into the case. This slider
shrinks the tab by 0 to 0.6 mm to give a looser fit. Leave it at 0 for a
snug fit and increase it if your printer makes the tab too tight.

**Blank panel.** The width of the blank panel part in HP, from 2 HP up to the
width of the case.

**Reset to defaults.** Puts every parameter back to its starting value
(26 HP, 30 mm front and rear, 1 mm round lips, symmetric, 6 HP panel) and
restores the default display colors.

---

## Assembly information

**Screws.** How many M3 screws hold the end caps on, for the whole case as set
now, split into floor, front and rear positions, with the total in brackets.
The number changes with the wall heights, because taller walls take more
screws, and with *Side panels*, because a symmetric case has two detachable ends
and needs twice as many. Each screw goes into a square nut trapped in the end
cap's tab, so you need as many **M3 square nuts** as screws.

---

## Export

**Format.** What kind of file to write for each part:

- *STL* — a mesh, for slicing and printing.
- *STEP* — an exact solid, for opening in CAD software.
- *Both* — one of each per part.

**Download.** Writes a zip file named `case.zip` containing every part ticked
under *Parts*, in the chosen format(s), plus a `config.json` recording the
settings that produced them. The note under the button always spells out what
you will get, for example "ZIP contains STLs of case mid section, two end caps,
blank panel, and config file."

If **no parts are ticked**, the note reads "No parts ticked. Config file only."
and the button downloads just `config.json`, on its own, as a plain JSON file.

Files inside the zip are named for the part and the settings that shape it,
so files from different cases never clash:

| file | meaning |
| --- | --- |
| `case_26hp_30mm-front_45mm-rear.stl` | case mid section, 26 HP, 30 mm front, 45 mm rear |
| `capL_30mm-front_45mm-rear.stl` | left end cap |
| `capR_30mm-front_45mm-rear.stl` | right end cap |
| `panel_6hp.stl` | 6 HP blank panel |
| `config.json` | the settings |

End caps carry no HP because their shape does not depend on the case width.

**More options** (click to expand). For downloading one part by itself:

- **Part** — which part to download: *Case*, *End cap, left*, *End cap, right*
  or *Blank panel*. The left cap is unavailable in the asymmetric variant,
  because that end is a fixed wall.
- **Format** — *STL* or *STEP*.
- **Download** — saves that one part as a bare file. No zip, no config file.

The status text beside a Download button shows the name and size of the file
that was just written, or an error if something went wrong.

---

## Config

**Import config.** Opens a file picker. Choose a `config.json` saved by this
page, either the one inside a downloaded `case.zip` (unzip it first) or one
downloaded on its own. Every control moves to the values in the file and the
case is rebuilt, so you can come back months later and reprint the same case,
or nudge one setting and reprint.

Only `.json` files are accepted. If the file is not one of ours, the status
text says so and nothing changes. If a value is missing, out of range or
mis-typed, the page corrects it to the nearest allowed value and lists each
correction in the status text, so you can see what was changed. The saved file
holds only the settings on this page; everything else about the case follows
the current model.

The file is plain text and can be edited by hand. It looks like this:

```json
{
  "format": "eurorack-case",
  "version": 1,
  "generated": "2026-09-03T02:25:00.000Z",
  "source": "https://github.com/daaaaaaaaaniel/eurorack-case",
  "parameters": {
    "hpCount": 26,
    "frontHeight": 30,
    "rearHeight": 30,
    "topLips": "round",
    "upperRound": 1,
    "upperChamfer": 1,
    "bottomLips": "round",
    "lowerRound": 1,
    "lowerChamfer": 1,
    "leftWall": false,
    "tabClearance": 0,
    "blankPanelHp": 6
  }
}
```

`leftWall: true` means the asymmetric variant. `topLips` and `bottomLips` are
`"round"`, `"sharp"` or `"chamfer"`, and the matching size is read from
`upperRound`/`upperChamfer` or `lowerRound`/`lowerChamfer`.

---

## Credits

Click **Credits** to expand the list of who made the case and the page.
"Supported by Synth Library NYC" is always shown, and links to their site.

---

## Printing the parts

1. Tick the parts you need, choose *STL*, and press **Download**.
2. Unzip `case.zip` and slice each `.stl`. Units are millimeters.
3. Keep `config.json` with your prints. Import it later to reprint or adjust.
4. Fit an M3 square nut into each trap in the end cap tabs, slide the caps on,
   and drive an M3 screw through each hole in the case. The *Assembly
   information* section tells you how many of each you need.

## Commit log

2026-09-02 Assess porting the Eurorack case FeatureScript to CadQuery
    Analyse the Onshape Part Studio export for `Eurorack v1 asym` and record a
    feasibility verdict, backed by a generated inventory and a runnable spike.
    The model is entirely prismatic (rectilinear profiles, blind extrudes,
    booleans, linear patterns, constant-radius fillets, equal-offset chamfers),
    so nothing in it needs geometry CadQuery cannot produce. What does not
    survive the move is Onshape's topological naming: 278 qCompressed queries
    identify edges and faces by construction history, which has no CadQuery
    equivalent and must be replaced by geometric selectors -- concentrated in
    the 7 fillet/chamfer features and the 24 edges they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
2026-09-02 Drop the PSU mounts and their dependents from the port scope
    The PSU mounting provisions belong to an older revision of the design and
    are not wanted, so they are out of scope rather than an open question.
    Suppression propagates silently: the export wraps every feature call in
    `try(...)`, so a live feature referencing suppressed geometry fails and is
    swallowed. Teach fs_inventory.py to follow that chain, which turns the four
    hard-suppressed features into ten dead ones -- Extrude 4/5, Sketch 5/7,
    Fillet 4 and the Ø2x5 hole go with them.
    That takes the fillet/chamfer features needing hand-written edge selectors
    from 7 to 6 (20 edges rather than 24) and the holes from 3 to 2, so it comes
    str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
2026-09-02 Port the Eurorack case to CadQuery
    Re-implement the Onshape Part Studio as a parametric CadQuery package that
    makes the same parts: the sloped-floor shell with T-slot rails, open at
    both ends; two end caps, each a 4 mm plate with a 5 mm tab that plugs into
    the shell and carries M3 nut traps behind every screw; and a blank test
    panel. CaseParams exposes the same nine configuration inputs as the Onshape
    configuration plus every design constant, named after the Onshape variable
    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
2026-09-02 Add a browser viewer with live parameter sliders
    viewer/make_viewer.py tessellates the four parts and embeds them into
    viewer/template.html as base64 vertex and index buffers, so the page needs
    no server and can be published as a self-contained artifact. The page draws
    them with Three.js under hand-rolled orbit controls (Z-up, matching the CAD
    frame), with part toggles, an explode slider, view presets and a readout of
    the derived dimensions.
    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
2026-09-02 Let the viewer save what it shows as STL
    Add an Export section to the viewer: pick a part (or everything shown),
    see its triangle count, and save an ASCII STL in millimetres of exactly
    what the scene is drawing, whether the embedded CadQuery mesh or the live
    preview. Explode offsets are not applied and the screw markers are skipped.
    STL is the only sensible format here: the page already holds triangle
    meshes, and STEP would need a B-rep kernel in the browser. Saving goes
    through the artifact host's downloads capability, which confirms with the
    viewer and whose extension allowlist has no .stl, so the file is offered
    as <name>.stl.txt with an on-page note to rename it. The section stays
    hidde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
2026-09-02 Verify against Onshape's STEP exports and add the asym variant
    Onshape's STEP exports of both Part Studios now live in reference/onshape/
    and tests/test_matches_onshape.py checks every part against them: volume
    to 1e-5, identical face counts and bounding extents. All five pass.
    Two corrections came out of the comparison. The rail block is 7.798 mm
    deep and its sliding-nut slot 5.597 mm wide -- both undimensioned in the
    source sketch, both carried by the export -- so rail_depth and a new
    rail_nut_slot_width default to those values rather than the 8 mm variable
    the sketch never references and the 5.7 mm nut-trap width. That closes the
    0.4 % volume gap on the shell.
    "sym" and "asym" turn out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
2026-09-02 Cut real holes and nut traps in the viewer's live preview
    The live preview built every part as a plain profile extrusion and only
    drew markers where the screws go, so the moment a control changed, the
    counterbores, through-holes and the tab's square nut traps disappeared --
    and because the STL export writes what the scene draws, a preview STL had
    none of them: the end cap came out 0.82 cm3 heavier than the exact part
    and would not assemble.
    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
2026-09-02 Map every Onshape variable to its CaseParams field
    Record the Part Studio's variable table against the port in
    docs/variables.md, marking the nine variables no live feature references
    and the two undimensioned values the sketches actually carry. BaseCase,
    which the export stores as '?', is 137.5 mm in Onshape: the outer depth,
    now exposed as outer_depth.
    Claude-Session: https://claude.ai/code/session_01TgJzqhknqW2EMbezAEupRA
2026-09-02 Port the case model to replicad
    web/ holds the model in TypeScript on replicad 1.0.1 (OpenCascade in
    wasm): caseParams() mirrors CaseParams field for field, and caseShell(),
    endCap() and blankPanel() are a line-for-line port of eurorack_case/parts.py.
    Edge selection for the lips uses replicad finders -- edges parallel to X
    inside a thin box along the target line, so the integral wall's collinear
    join is caught too -- and the cap's outer-face chamfer selects edges in the
    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
    [asym-case.step, asym-endcap.step, sym-case.step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]
2026-09-02 Add the browser configurator and its GitHub Pages deploy
    A Vite + TypeScript app around the replicad model. OpenCascade runs in a
    web worker (src/worker.ts): it builds the parts on request, returns
    meshes, edge lines and volumes, and writes binary STL or STEP on demand,
    so downloads are real files with real extensions. The viewer (src/scene.ts,
    src/main.ts, index.html) carries over the panel, readout, explode and view
    presets from the artifact viewer, on three.js with OrbitControls, Z-up.
    Every control change rebuilds the B-rep model; the status line shows the
    build time and a failed worker surfaces as a banner rather than a spinner.
    scripts/smoke.mjs drives the built app in headless Chromi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
2026-09-02 Keep the configurator sound at every lip size
    Moving the top-lip slider past 4 mm crashed the page with a bare
    WebAssembly.Exception: the wall top is only the wall's thickness wide before
    it drops into the panel recess, so a fillet that large has no face to land
    on. Worse, several sizes the sliders allowed made the end cap come back as a
    plausible-looking solid with a wrong volume, or empty, without any error:
    OpenCascade cannot blend a large lip into the plate's 1.5 mm outer edge
    break.
    - caseParams() refuses a top lip at or above the wall thickness, and the
    page's slider stops at 3.5 mm.
    - endCap() builds the outer-face break only while the lips are modest
    (rounds to 5 mm, chamfers to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
2026-09-02 Add an editable session prompt and the agent that maintains it
    A session's system prompt is fixed when the session starts, so nothing can
    rewrite it from inside. A UserPromptSubmit hook is the nearest equivalent: it
    injects text on every turn, and the text comes from a file, so editing the file
    is the whole update mechanism.
    - .claude/session-prompt.md holds the standing context that would otherwise be
    re-derived every session: which branch owns which implementation, the rule
    that the replicad branch leaves the CadQuery model alone, the geometry frame,
    the three reference volumes verified against the Onshape exports, the checks
    to run before a push, and the open web-interface work.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
2026-09-02 Refine the configurator's side panel
    - Parts gains a "Selected total" line: the volume of whatever is ticked,
    updated from the checkboxes without a rebuild.
    - A Display section collects the two colours and Explode. The case colour
    drives both the shell material and the UI accent, the second colour the
    end caps; a picked colour is written as an inline custom property on
    :root, so the panel swatches, the accent and the three.js materials all
    follow, and Reset puts the stylesheet's own colours back.
    - The variant control reads "Side panels", with the options named for
    which ends come off: "Symmetric (both detachable)" and "Asymmetric
    (right detachable)". The status line says symme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
2026-09-03 Download the parts as a zip, and import a saved config
    Saving a whole case meant pressing Save four times, and the settings that
    produced the files lived nowhere — come back a month later and the
    configuration was gone.
    Export is now one Download button and a format (STL, STEP or both). It
    writes the parts ticked under Parts: one part in one format comes down as
    itself, anything more as case.zip carrying a config.json of the settings.
    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
2026-09-03 Reword the configurator's panel and title
    - The page is "Eurorack Case Preview"; the status line puts "built in" on
    its own line under the case summary.
    - The download note names what the zip will hold: "ZIP contains STLs of
    case mid section, two end caps, blank panel, and config file", counted
    from the ticked parts and the chosen formats.
    - Rail bolt spacing leaves the readout. It is panel height less twice the
    rail inset, both fixed, so it read 123.5 mm whatever the sliders said.
    - The color note under Display is gone; the heading carries a small "i"
    instead, which shows "Display settings only affect the web preview
    rendering. They have no impact on actual generated parts." on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
2026-09-03 Put Display first, add Credits, drop the rebuild note
    - Display moves above Parts, so the view settings sit at the top of the
    panel.
    - The "i" beside the Display heading is centered on the text: the heading
    is a flex row and the button centers its glyph.
    - A Credits section closes the panel: 3D modeling and design, developers,
    web interface, and Synth Library NYC, whose link opens in a new tab.
    - The paragraph about rebuild behavior and lip limits is gone.
    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
2026-09-03 Add a Parts tip, fold the credits, and show LOADING on first start
    - Parts gets the same "i" as Display: "Unselected parts are hidden from
    view and excluded from ZIP export." The tip wiring now runs over every
    .tip on the page rather than one id.
    - Credits collapses like More options, closed by default. "Supported by
    Synth Library NYC" sits outside the fold so it always shows.
    - While OpenCascade starts, LOADING sits large in the centre of the canvas,
    its three dots stepping in one at a time. That is one element and one
    CSS animation clipping a fixed "..." to 0, 1, 2 and 3 characters, so it
    costs nothing on the load path; it is hidden once the first model is up,
    and holds still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
2026-09-03 Fold the readout into the parameters and an assembly section
    The Readout listed six measurements at the bottom of the panel, away from
    the controls that set them. Now each sits with its control:
    - Under Width: the assembled length with end caps and the case length
    without. An integral left wall takes the same 4 mm a cap would, so the
    assembled length is the same in both variants and the case on its own is
    4 mm longer in the asymmetric one.
    - Under Rear height: "Panel tilts 20.0° toward front", or "Panel is level".
    - Depth and Height are gone: depth is fixed by the model and height only
    repeated the sliders.
    What remains is an Assembly information section above Export: the screw
    co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
2026-09-03 Right-align the length and tilt lines
    The lines under Width and Rear height sit against the right edge, under
    the values they qualify. The bare case length comes first, as a number
    alone, with the assembled length "with end caps" beneath it.
    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
2026-09-03 Always zip the main download, and serve the config alone when nothing is ticked
    Download used to hand over a bare file when one part in one format was
    asked for, which left that download without its configuration. Now every
    press of Download writes case.zip with a config.json inside, however few
    parts are ticked. With nothing ticked there is no geometry to write, so
    the page serves the config.json on its own, as raw JSON built on the main
    thread, and the note under the button says "No parts ticked. Config file
    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
2026-09-03 Let the title and hint be selected, and shorten the single-part note
    The title, status line and the orbit hint over the canvas carried
    pointer-events: none so a drag begun on them would still orbit. That also
    made them impossible to select or copy. The rule is gone; they are
    ordinary text now, and a drag has the rest of the canvas to start on. The
    smoke run checks a click at each lands on the text and not the canvas.
    Under More options the button reads Download and the note says "STL file
    for an individual part. No config.", following the format chosen.
    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
2026-09-03 Add a user manual for the web page
    UserManual.md walks through every control on the browser configurator in
    the order the panel shows them: the 3D view and its buttons, Display,
    Parts, each Parameter with its range and what it does to the case,
    Assembly information, Export and the zip's contents and file names, More
    options, Config import with an annotated example file, Credits, and a
    short printing checklist. The root README points to it.
    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
